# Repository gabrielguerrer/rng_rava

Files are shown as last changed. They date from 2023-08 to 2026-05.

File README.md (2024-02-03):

# RAVA: an Open Hardware True Random Number Generator based on Avalanche Noise

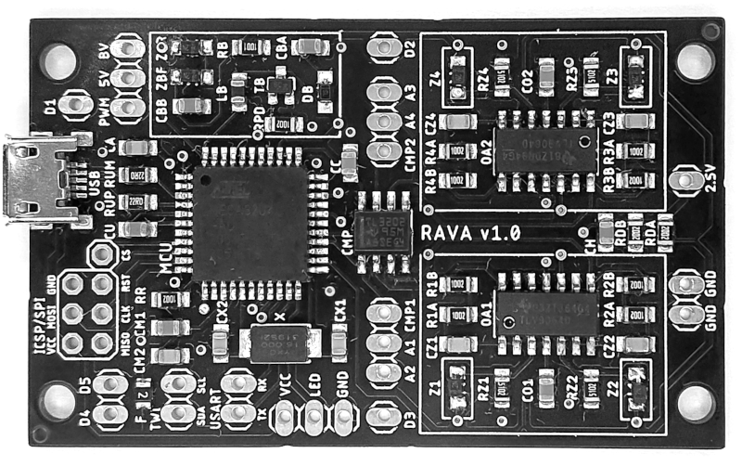
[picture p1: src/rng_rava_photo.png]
RAVA photo


RAVA is an open-source True Random Number Generator (TRNG) designed to offer a transparent and customizable platform, making auditalbe and high-quality entropy accessible to a wider audience. 
The RAVA device's main characteristics are:

- High-quality entropy: Producing unbiased and independent random bits without a post-processing algorithm.

- Differential design: Aiming towards immunity to environmental conditions by comparing two similar and independent noise sources.

- Dual entropy core: Incorporating two parallel and independent entropy channels that simultaneously produce random bytes. The dual design provides redundancy, a double output rate, or a unique feature for experiments employing a condition/control design.

- Full transparency: As an open-source project providing complete access to the circuit design, firmware, and user-side software, including drivers, libraries, and utilities.  At the hardware level, monitoring headers allow real-time inspection of voltages and noise sources during operation.

- Customizability: Offering interface headers for integration with other circuits, sensors, and integrated circuit (IC) components. Users have full control over the device's operation by sending commands through a communication interface. Moreover, as an open-source project, the firmware can be updated to modify the circuit's behavior and implement new functionalities.

- Accessibility: As a discrete circuit employing low-cost IC components and SMD resistors and capacitors of size 0805. Ensuring that the device remains affordable and can be assembled by users through manual soldering of the components to the printed circuit board. 

## Publication

For a comprehensive overview, encompassing an in-depth exploration of the noise source, a stochastic model, and statistical tests, please consult the article
- [IEEE Access, DOI: 10.1109/ACCESS.2023.3327325](https://ieeexplore.ieee.org/document/10295491)

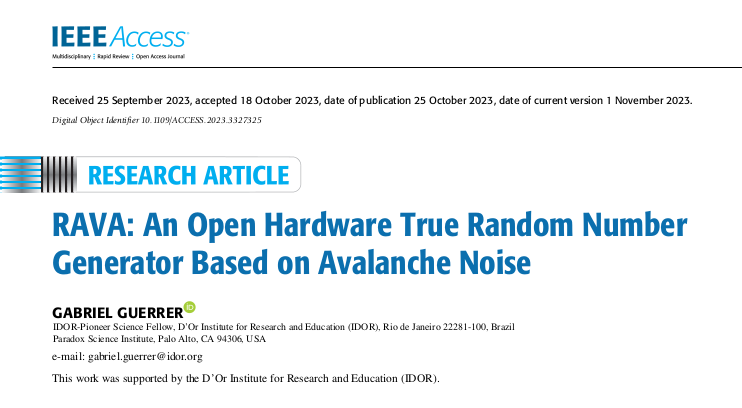
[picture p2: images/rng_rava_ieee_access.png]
IEEE Access article


## Schematics

The v1.0 implementation is presented as a discrete circuit with an ATmega32U4 microcontroller and a USB interface, achieving an unbiased throughput of 136.0 Kbits/s.

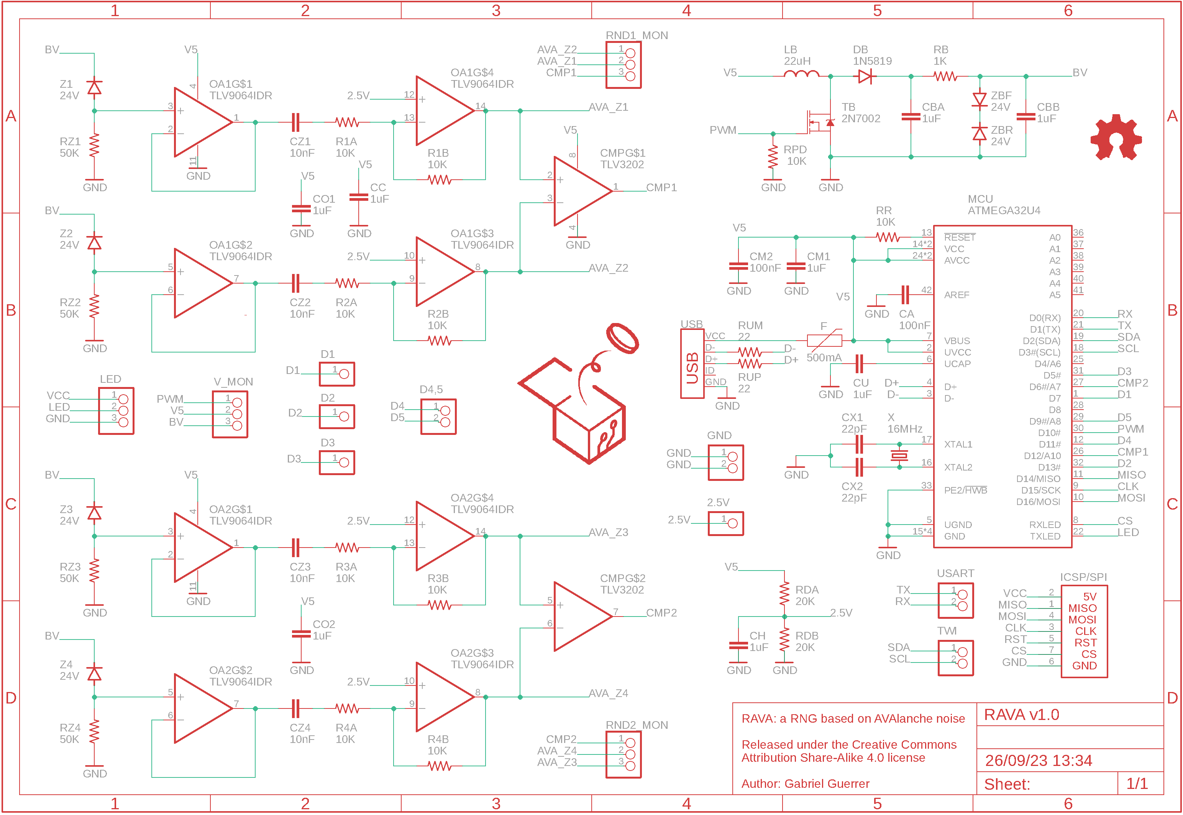
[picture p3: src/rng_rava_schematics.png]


## Entropy

The physical phenomenon associated with the RAVA circuit’s entropy is the avalanche breakdown of reverse-biased diodes and the time unpredictability of those events.

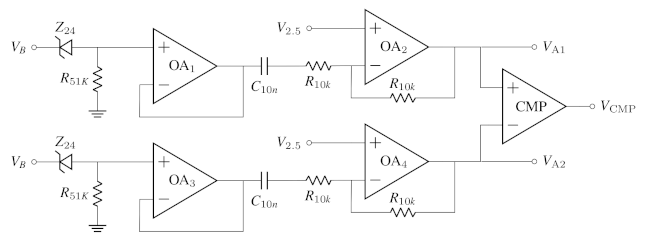
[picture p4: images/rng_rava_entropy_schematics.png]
RAVA entropy schematics


A 25.5V voltage is applied to two reverse-biased 24V Zener diodes, inducing avalanche breakdown.
Next, the noise voltages are buffered using operational amplifiers (OA1, OA3). The purpose of the buffering stage is to prevent distortions that could be introduced in the subsequent steps.
The noise voltages are then DC decoupled and raised to a common level of 2.5V using unity-gain operational amplifiers (OA2, OA4). 
These operations result in the *avalanche noise* channels V_A1 and V_A2 containing the original noise voltages, which have been inverted and raised to the 2.5V DC level.

Finally, the analog channels V_A1 and V_A2 are connected to a comparator IC, which produces a digital output V_CMP representing which Zener produces the largest avalanche noise at a given time.
The V_CMP output, referred to as *differential noise*, consists of a sequence of pulses with varying lengths and unknown rising edge times. 
The interval between successive pulses depends on the avalanche breakdown occurring in the reverse-biased Zener diodes. 
Consequently, the pulses' intervals are inherently unpredictable, serving as an entropy source for the circuit.

Below is an example showcasing data for V_A1, V_A2, and V_CMP

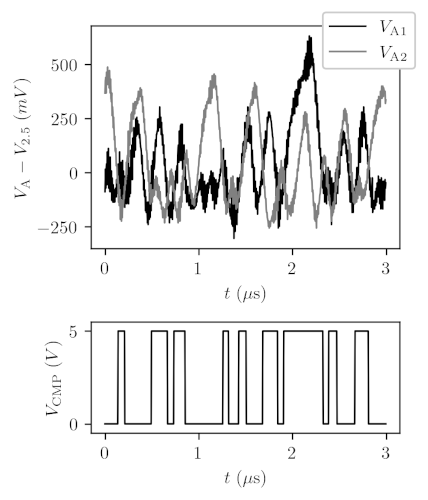
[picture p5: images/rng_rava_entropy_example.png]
RAVA entropy example


The noise source output V_CMP is wired to a timer/counter port in the microcontroller configured to count the measured rising edge pulses.
Every ith-random bit is generated by evaluating the *pulse count* after a fixed *sampling interval*. 
The i-th bit results in 0 if the pulse count is even and 1 if odd.
The example reveals nine pulses in the sampling interval of 3 mus that would result in a 1 bit.

## Documentation

- [RAVA ‐ Assembling and Inspecting](https://github.com/gabrielguerrer/rng_rava/wiki/RAVA-Device-%E2%80%90-Assembling-and-Inspecting)
- [RAVA Firmware ‐ Installation](https://github.com/gabrielguerrer/rng_rava_firmware/wiki/RAVA-Firmware-%E2%80%90-Installation)
- [RAVA Firmware ‐ How it works](https://github.com/gabrielguerrer/rng_rava_firmware/wiki/RAVA-Firmware-%E2%80%90-How-it-works)
- [RAVA Python Driver - Installation and Usage](https://github.com/gabrielguerrer/rng_rava_driver_py)
- [RAVA Python Diagnostics - Statistical Tests](https://github.com/gabrielguerrer/rng_rava_diagnostics_py/wiki/Statistical-Tests)

## Associated projects

- [RAVA Firmware](https://github.com/gabrielguerrer/rng_rava_firmware)
- [RAVA Python Driver](https://github.com/gabrielguerrer/rng_rava_driver_py)
- [RAVA Python Diagnostics](https://github.com/gabrielguerrer/rng_rava_diagnostics_py)

## Contact

gabrielguerrer [at] gmail [dot] com

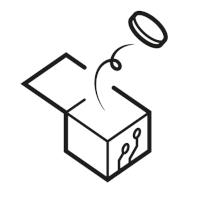
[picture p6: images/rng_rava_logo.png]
RAVA logo


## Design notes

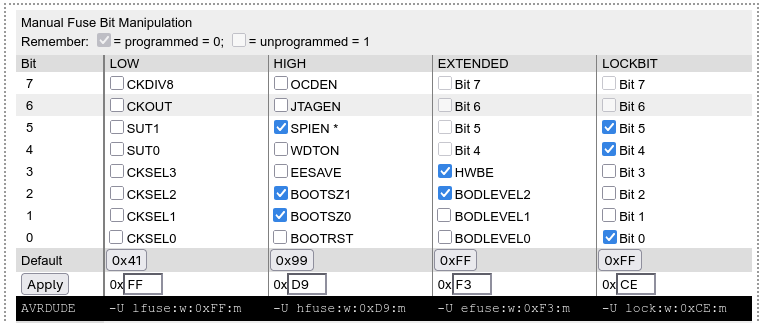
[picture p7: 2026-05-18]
images/wiki_mcu_fuses.png

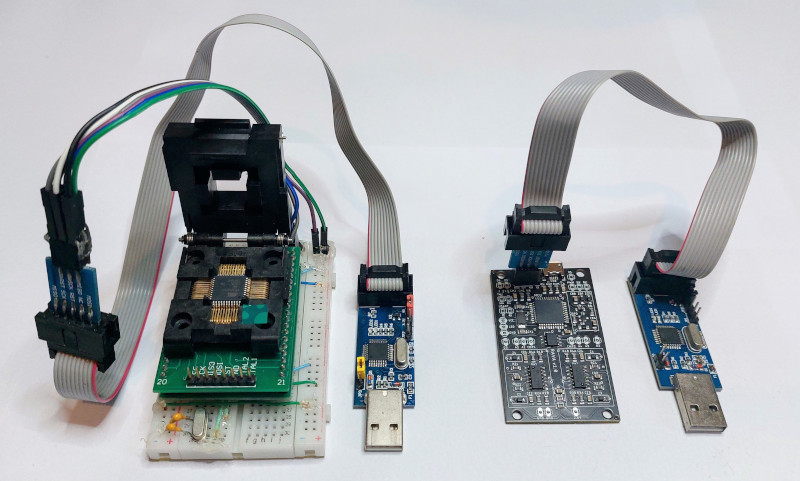
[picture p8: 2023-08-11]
images/wiki_mcu_spi_usbasp.jpg

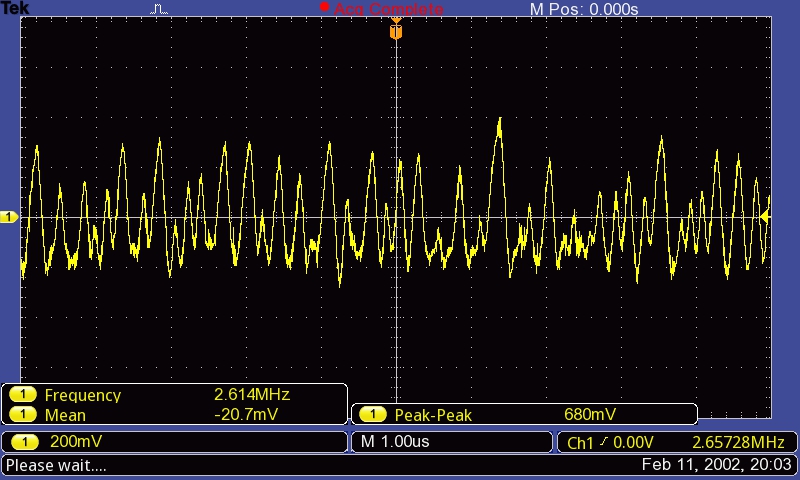
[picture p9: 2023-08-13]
images/wiki_inspect_avalanche_ac.jpg

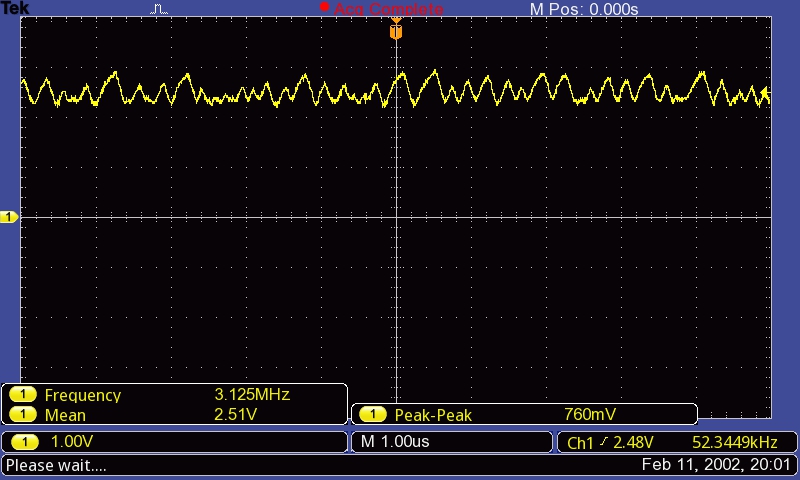
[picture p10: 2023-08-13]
images/wiki_inspect_avalanche_dc.jpg

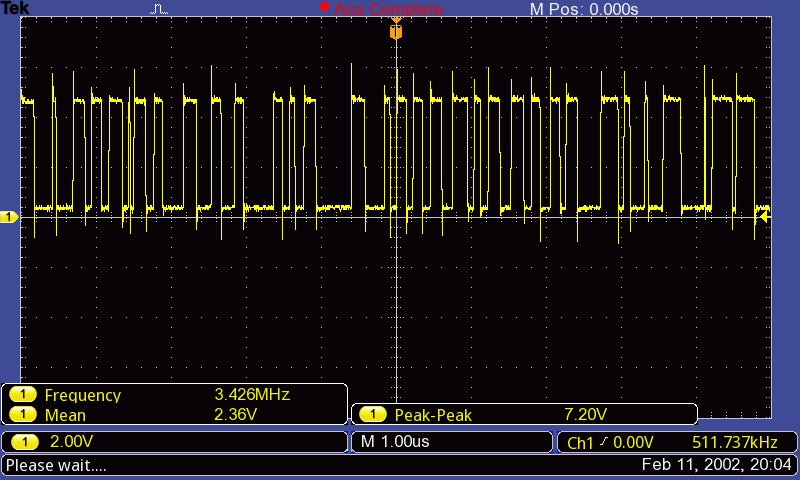
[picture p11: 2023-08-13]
images/wiki_inspect_differential_dc.jpg

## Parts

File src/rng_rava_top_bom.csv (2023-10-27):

Comment | Designator | Quantity | Footprint | Mfr Part # | LCSC Part #
1K | RB | 1 | 805 | 0805W8F1001T5E | C17513
1N5819 | DB | 1 | SOD-323 | 1N5819WS | C369937
1uF | CBA CBB CC CH CM1 CO1 CO2 CU | 8 | 805 | CL21B105KBFNNNE | C28323
2N7002 | TB | 1 | SOT323 | K2N7002W-7-F | C2891696
10K | R1A R1B R2A R2B R3A R3B R4A R4B RPD RR | 10 | 805 | 0805W8F1002T5E | C17414
10nF | CZ1 CZ2 CZ3 CZ4 | 4 | 805 | CL21B103KBANNNC | C1710
16MHz | X | 1 | SMD_5032 | X503216MSB2GI | C112572
20K | RDA RDB | 2 | 805 | 0805W8F2002T5E | C4328
22 | RUM RUP | 2 | 805 | 0805W8F220JT5E | C17561
22pF | CX1 CX2 | 2 | 805 | CL21C220JBANNNC | C1804
22uH | LB | 1 | 805 | CB2012T220K | C223175
24V | Z1 Z2 Z3 Z4 ZBF ZBR | 6 | SOD-323 | MM3Z24 | C118615
50K | RZ1 RZ2 RZ3 RZ4 | 4 | 805 | 0805W8F5102T5E | C17737
100nF | CA CM2 | 2 | 805 | CL21B104KBCNNNC | C1711
500mA | F | 1 | 805 | BSMD0805-020-30V | C883105
ATMEGA32U4 | MCU | 1 | TQFP44 | ATMEGA32U4-AU | C44854
C40957 | USB | 1 | U254-051N-4BH806 | U254-051N-4BH806 | C319170
TLV3202 | CMP | 1 | SOIC8 | TLV3202AIDR | C129325
TLV9064IDR | OA1 OA2 | 2 | SOIC127P600X175-14N | TLV9064IDR | C388176

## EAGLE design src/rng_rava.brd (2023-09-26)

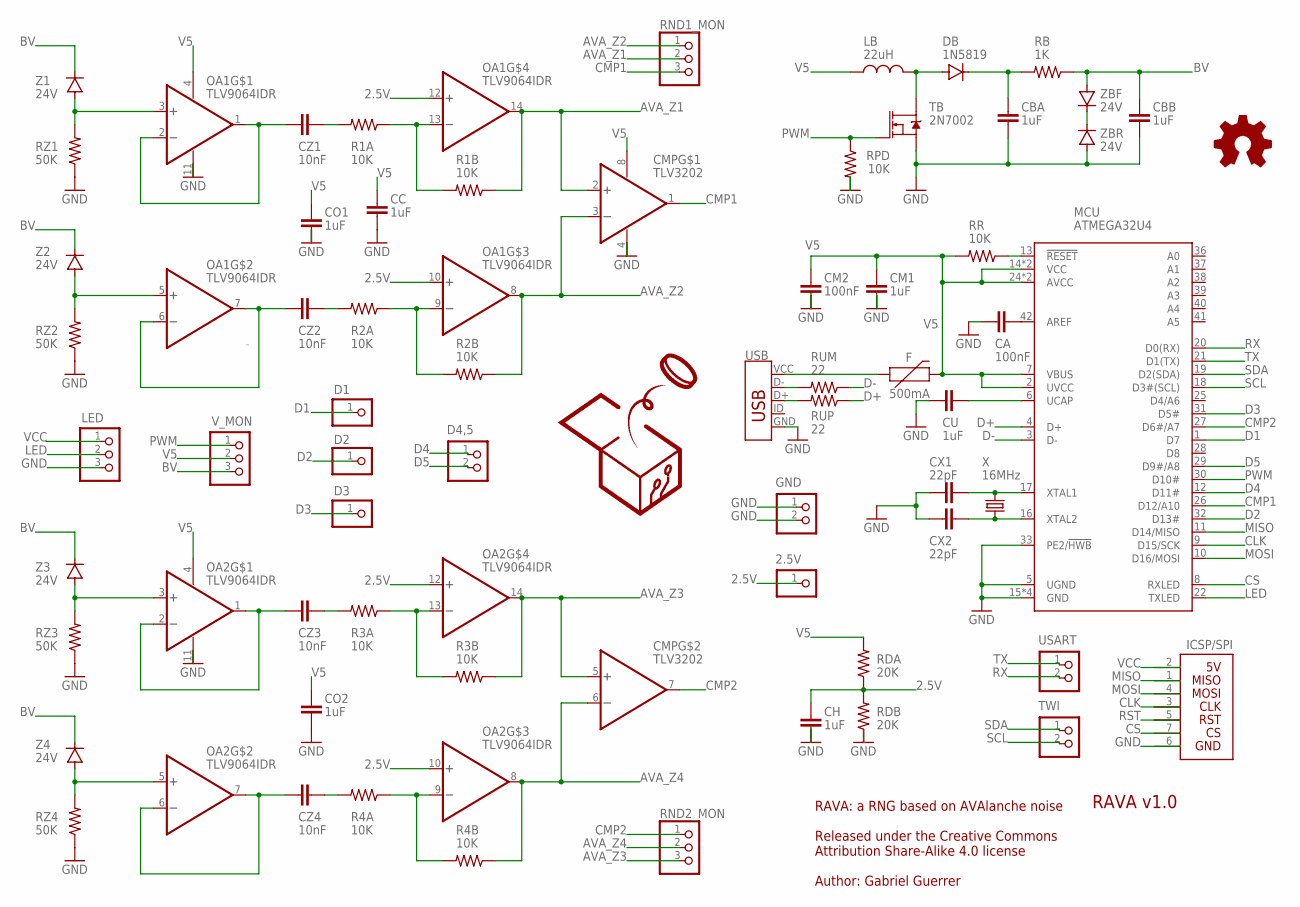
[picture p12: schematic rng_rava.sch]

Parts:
2.5V: PINHD-1X1LARGE; 1X01LARGE
CA: 100nF; 0805; LCSC_PART C28323
CBA: 1uF; 0805; LCSC_PART C28323
CBB: 1uF; 0805; LCSC_PART C28323
CC: 1uF; 0805; LCSC_PART C28323
CH: 1uF; 0805; LCSC_PART C28323
CM1: 1uF; 0805; LCSC_PART C28323
CM2: 100nF; 0805; LCSC_PART C28323
CMP: TLV3202; SOIC8; LCSC_PART C129325
CO1, CO2: 1uF; 0805; LCSC_PART C28323
CU: 1uF; 0805; LCSC_PART C28323
CX1, CX2: 22pF; 0805; LCSC_PART C1804
CZ1, CZ2, CZ3, CZ4: 10nF; 0805; LCSC_PART C1710
D1, D2, D3: PINHD-1X1LARGE; 1X01LARGE
D4,5: PINHD-1X2; 1X02
DB: 1N5819; SOD-323; LCSC_PART C369937
F: 500mA; 0805
GND: PINHD-1X2; 1X02
ICSP/SPI: ICSP-CS; 2X04
LB: 22uH; 0805; LCSC_PART C223170
LED: PINHD-1X3; 1X03
MCU: ATMEGA32U4; TQFP44; LCSC_PART C44854
OA1, OA2: TLV9064IDR; SOIC127P600X175-14N; LCSC_PART C388176
R1A, R1B, R2A, R2B, R3A, R3B, R4A, R4B: 10K; 0805; LCSC_PART C276215
RB: 1K; 0805; LCSC_PART C317261
RDA: 20K; 0805; LCSC_PART C4328
RDB: 20K; 0805; LCSC_PART C4328
RND1_MON, RND2_MON: PINHD-1X3; 1X03
RPD: 10K; 0805; LCSC_PART C317261
RR: 10K; 0805; LCSC_PART C276215
RUM: 22; 0805; LCSC_PART C17561
RUP: 22; 0805; LCSC_PART C17561
RZ1, RZ2, RZ3, RZ4: 50K; 0805; LCSC_PART C276216
TB: 2N7002; SOT323; LCSC_PART C139444
TWI: PINHD-1X2; 1X02
USART: PINHD-1X2; 1X02
USB: C40957; U254-051N-4BH806; LCSC_PART C319170
V_MON: PINHD-1X3; 1X03
X: 16MHz; SMD_5032; LCSC_PART C115962
Z1, Z2, Z3, Z4: 24V; SOD-323; LCSC_PART C118615
ZBF: 24V; SOD-323; LCSC_PART C118615
ZBR: 24V; SOD-323; LCSC_PART C118615

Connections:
2.5V: 2.5V.1, CH.2, OA1.10 (+IN), OA1.12 (+IN), OA2.10 (+IN), OA2.12 (+IN), RDA.1, RDB.2
AVA_Z1: CMP.2 (+IN), OA1.14 (OUT), R1B.1, RND1_MON.2
AVA_Z2: CMP.3 (-IN), OA1.8 (OUT), R2B.1, RND1_MON.1
AVA_Z3: CMP.5 (+IN), OA2.14 (OUT), R3B.1, RND2_MON.3
AVA_Z4: CMP.6 (-IN), OA2.8 (OUT), R4B.1, RND2_MON.2
BV: CBB.1, RB.1, V_MON.3, Z1.C, Z2.C, Z3.C, Z4.C, ZBF.A
CLK: ICSP/SPI.3 (CLK), MCU.9 (D15/SCK)
CMP1: CMP.1 (OUT), MCU.26 (D12/A10), RND1_MON.3
CMP2: CMP.7 (OUT), MCU.27 (D6#/A7), RND2_MON.1
CS: ICSP/SPI.7 (CS), MCU.8 (RXLED)
D1: D1.1, MCU.1 (D7)
D2: D2.1, MCU.32 (D13#)
D3: D3.1, MCU.31 (D5#)
D4: D4,5.1, MCU.12 (D11#)
D5: D4,5.2, MCU.29 (D9#/A8)
D+: MCU.4 (D+), RUP.1
D-: MCU.3 (D-), RUM.1
GND: CA.1, CBA.2, CBB.2, CC.2, CH.1, CM1.1, CM2.1, CMP.4 (GND), CO1.2, CO2.2, CU.1, CX1.2, CX2.2, GND.1, GND.2, ICSP/SPI.6 (GND), LED.3, MCU.5 (UGND), MCU.15 (GND), MCU.23 (GND), MCU.33 (PE2/!HWB), MCU.35 (GND), MCU.43 (GND), OA1.11 (GND), OA2.11 (GND), RDB.1, RPD.2, RZ1.1, RZ2.1, RZ3.1, RZ4.1, TB.2 (S), USB.GND, ZBR.A
LED: LED.2, MCU.22 (TXLED)
MISO: ICSP/SPI.1 (MISO), MCU.11 (D14/MISO)
MOSI: ICSP/SPI.4 (MOSI), MCU.10 (D16/MOSI)
unnamed: CZ1.2, R1A.2
unnamed: CZ1.1, OA1.1 (OUT), OA1.2 (-IN)
unnamed: OA1.3 (+IN), RZ1.2, Z1.A
unnamed: OA1.13 (-IN), R1A.1, R1B.2
unnamed: CZ2.1, OA1.6 (-IN), OA1.7 (OUT)
unnamed: OA1.5 (+IN), RZ2.2, Z2.A
unnamed: CZ2.2, R2A.2
unnamed: OA1.9 (-IN), R2A.1, R2B.2
unnamed: CZ3.1, OA2.1 (OUT), OA2.2 (-IN)
unnamed: OA2.3 (+IN), RZ3.2, Z3.A
unnamed: CZ3.2, R3A.2
unnamed: OA2.13 (-IN), R3A.1, R3B.2
unnamed: CZ4.1, OA2.6 (-IN), OA2.7 (OUT)
unnamed: OA2.5 (+IN), RZ4.2, Z4.A
unnamed: CZ4.2, R4A.2
unnamed: OA2.9 (-IN), R4A.1, R4B.2
unnamed: DB.A, LB.2, TB.3 (D)
unnamed: CBA.1, DB.C, RB.2
unnamed: ZBF.C, ZBR.C
unnamed: CU.2, MCU.6 (UCAP)
unnamed: RUM.2, USB.D-
unnamed: RUP.2, USB.D+
unnamed: CX1.1, MCU.17 (XTAL1), X.P$2 (2)
unnamed: CX2.1, MCU.16 (XTAL2), X.P$1 (1)
unnamed: CA.2, MCU.42 (AREF)
PWM: MCU.30 (D10#), RPD.1, TB.1 (G), V_MON.1
RST: ICSP/SPI.5 (RST), MCU.13 (!RESET), RR.1
RX: MCU.20 (D0(RX)), USART.2
SCL: MCU.18 (D3#(SCL)), TWI.2
SDA: MCU.19 (D2(SDA)), TWI.1
TX: MCU.21 (D1(TX)), USART.1
V5: CC.1, CM1.2, CM2.2, CMP.8 (VCC), CO1.1, CO2.1, F.2, LB.1, MCU.2 (UVCC), MCU.7 (VBUS), MCU.14 (VCC), MCU.24 (AVCC), MCU.34 (VCC), MCU.44 (AVCC), OA1.4 (VCC), OA2.4 (VCC), RDA.2, RR.2, V_MON.2
VCC: F.1, ICSP/SPI.2 (VCC_3V), LED.1, USB.VCC (VBUS)

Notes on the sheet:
RAVA: a RNG based on AVAlanche noise Released under the Creative Commons Attribution Share-Alike 4.0 license Author: Gabriel Guerrer
RAVA v1.0

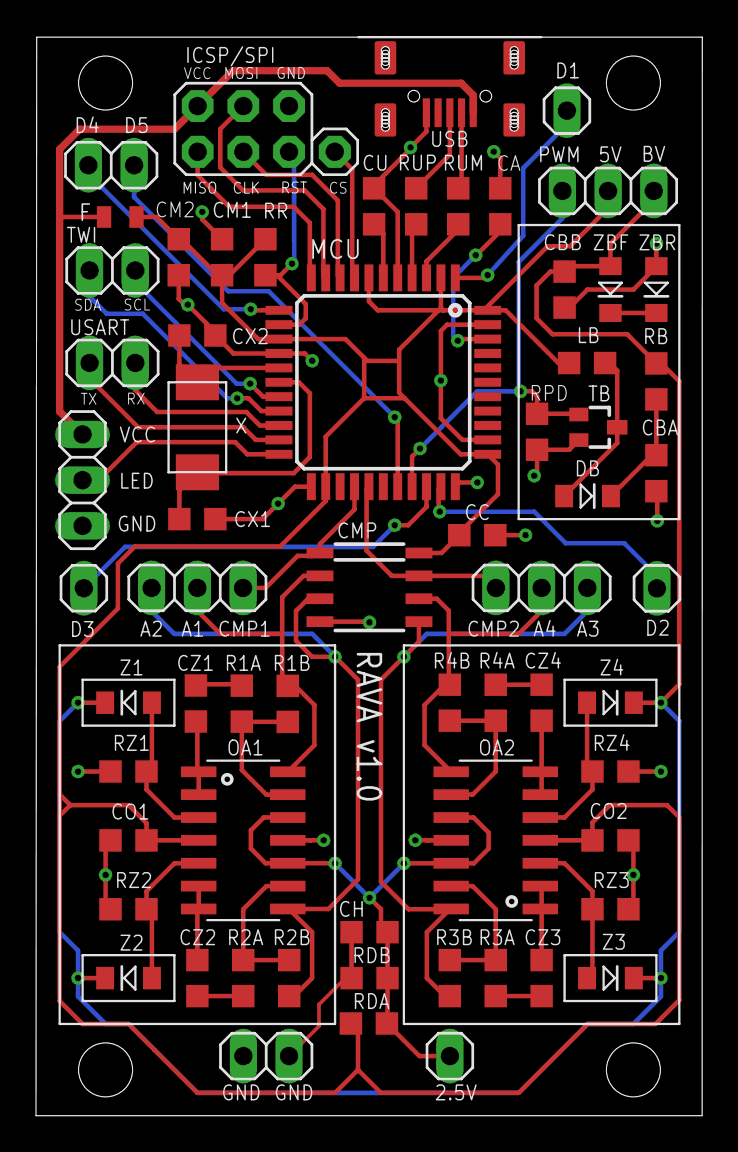
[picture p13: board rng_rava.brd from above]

Board: 2 copper layers, 37.0 x 59.9 mm, 64 parts (0 on the bottom side), 54 nets.

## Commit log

2023-08-09 First upload
    [rng_rava.brd, rng_rava.sch, rng_rava_top_bom.csv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]
2023-08-12 bom v10 mfr part
    [rng_rava_top_bom.csv]
2023-09-26 updating peripherals
    [rng_rava.brd, rng_rava.sch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]
2023-10-27 BOM: Including Quantity
    [rng_rava_top_bom.csv]
2026-04-29 updating fuse image
2026-05-18 Updating fuses image

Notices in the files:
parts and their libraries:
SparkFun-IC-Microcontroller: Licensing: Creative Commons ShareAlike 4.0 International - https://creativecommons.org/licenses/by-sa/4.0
